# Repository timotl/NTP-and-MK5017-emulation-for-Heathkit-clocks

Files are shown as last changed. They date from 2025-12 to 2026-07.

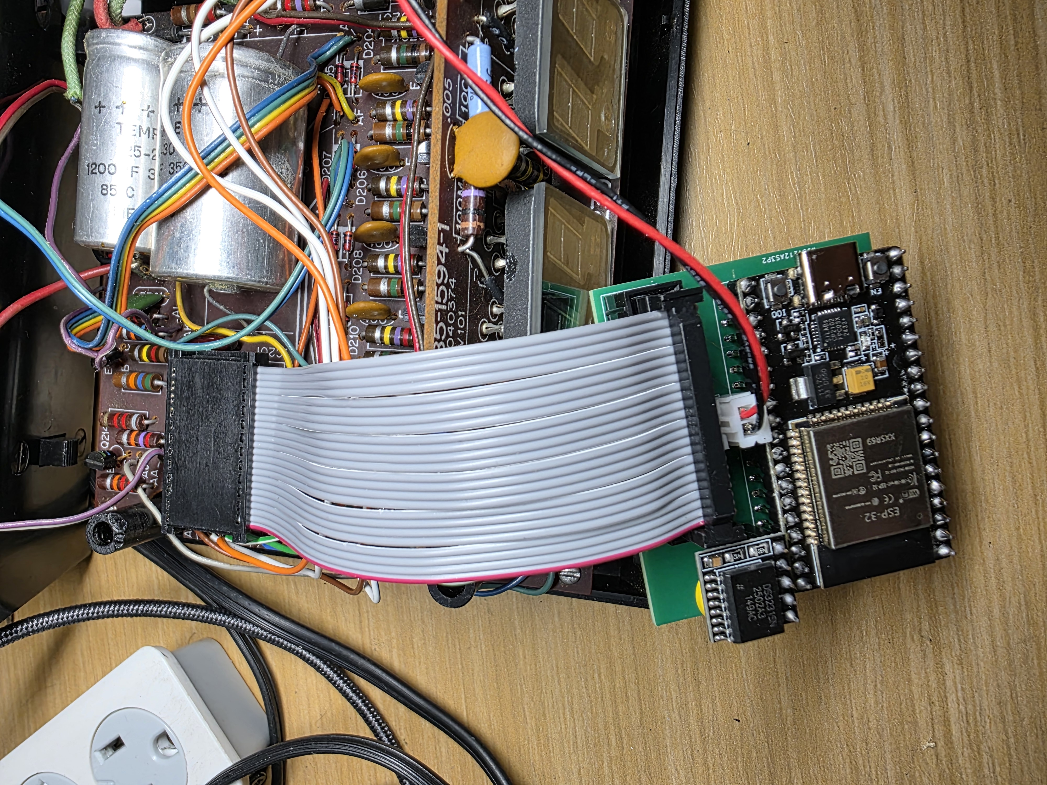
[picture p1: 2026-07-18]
Pictures/PCB Installed.jpg

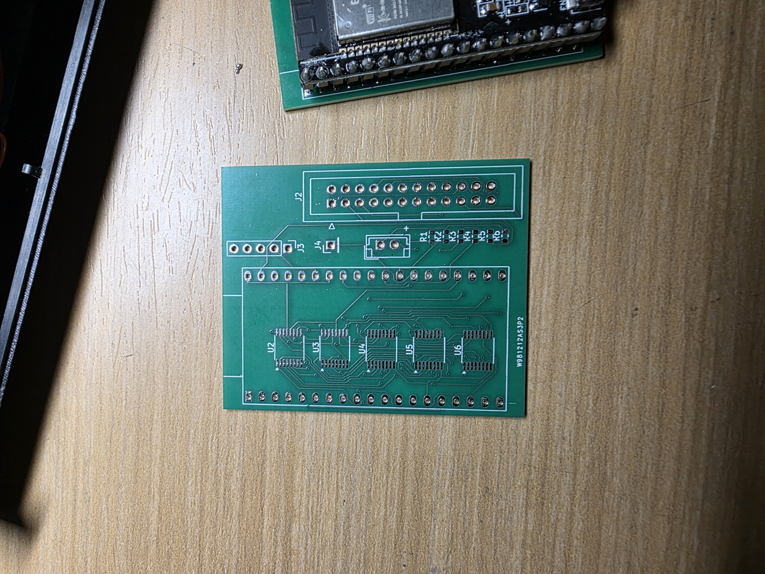
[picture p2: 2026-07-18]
Pictures/PCB Top.jpg

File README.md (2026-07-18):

# NTP-and-MK5017-emulation-for-Heathkit-clocks
Documentation and modification of original clock to use ESP32 module instead of MK5017. 
Uses original chip socket and only requires 5v power module. 
No additional changes to the original hardware. 
Includes schematic and PCB for interface board. 
Full code and description of function. 
Documentation of the MK5017 

ESP32 sketch to replace MK5017AA and BA used in HeathKit panaplex clocks
Requires shift register and level shifting interface which connects to the original board via chip socket
No modifications to the original clock, except adding a 5v power supply module at the 120v input line
Heathkit GC-1092D, Heathkit GC-1005, Heathkit GC-1092A, Heathkit GC-1094 all fully tested
Display updates are state driven and writing to display is handled by hardware timer

WIFI mode:
Portal will be active if the configured wifi settings do not connect or if the time cannot be set from the configured NTP server after 1 minute.
NTP server, timezone, display off times are set through the portal.

ESP Touch (also snooze or alarmoff switches) changes display from Time to Date, Date to display off, display off to on.
GC-1092A/D - Original 555 touch hardware can be used, however each touch event must be at least 5 seconds apart.

MK5017 mode:
Switches and all behavior faithful to original hardware
RTC simulates battery backup of the GC-1092A/D (but works on all models) - Will consider time valid for configurable number of hours.
Note: some RTC modules don't keep time when powered off. Set BatteryBackup to 0 to disable holdover.
Switching modes will reset the model. Set model by pressing Hour/Month switch until the correct model is displayed, then toggle Time Set.

Switching modes:
Holding Hour/Month switch at power up will change between MK5017 and Wifi mode. Display will go from 888888 to ------ and restart

ArduinoOTA mode:
Alarm/Date switch also enters OTA mode. OTA mode uses AP mode with password and times out after 10 min.

Troubleshooting - Toggle Time Set switch 3x in under 5 seconds.
WIFI mode: Restart to portal to adjust WIFI and NTP settings.
MK5017 mode: Restart clearing RTC and model

Select ESP32-WROOM-DA Module in Arduino IDE
Partition scheme "Minimal SPIFFS (1.9MB APP with OTA/190KB SPIFFS) required if SerialBT is enabled

Also includes Manuals and other datasheets for the various models I can find.

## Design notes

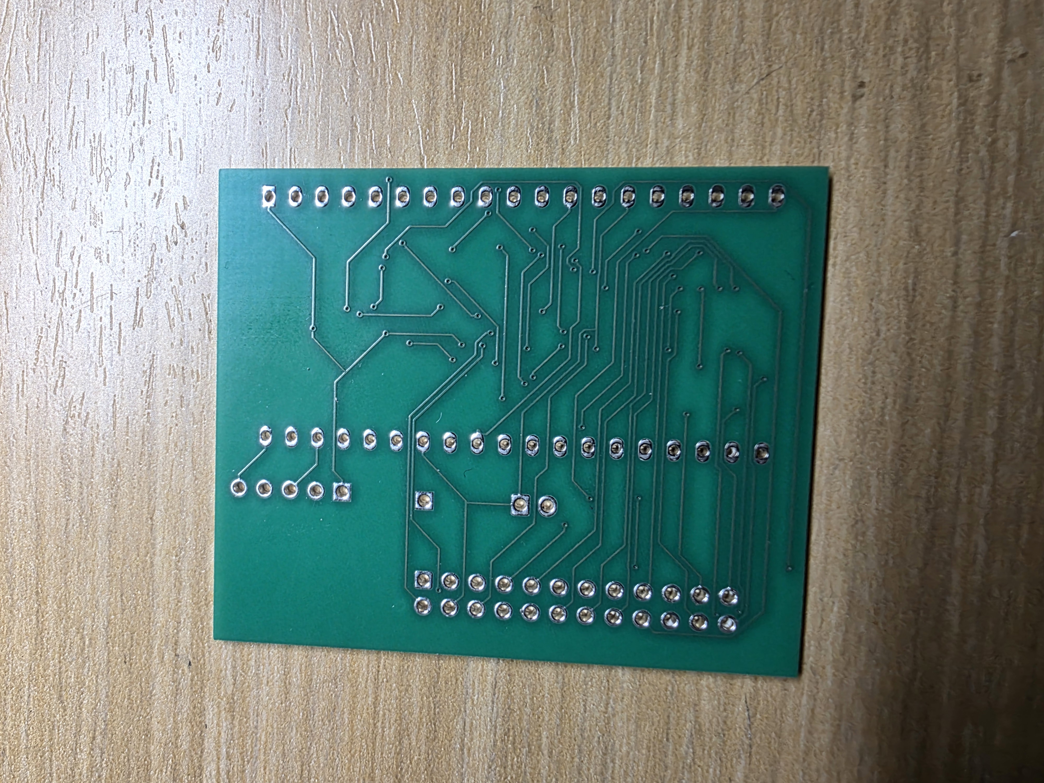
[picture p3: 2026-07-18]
Pictures/PCB Bottom.jpg

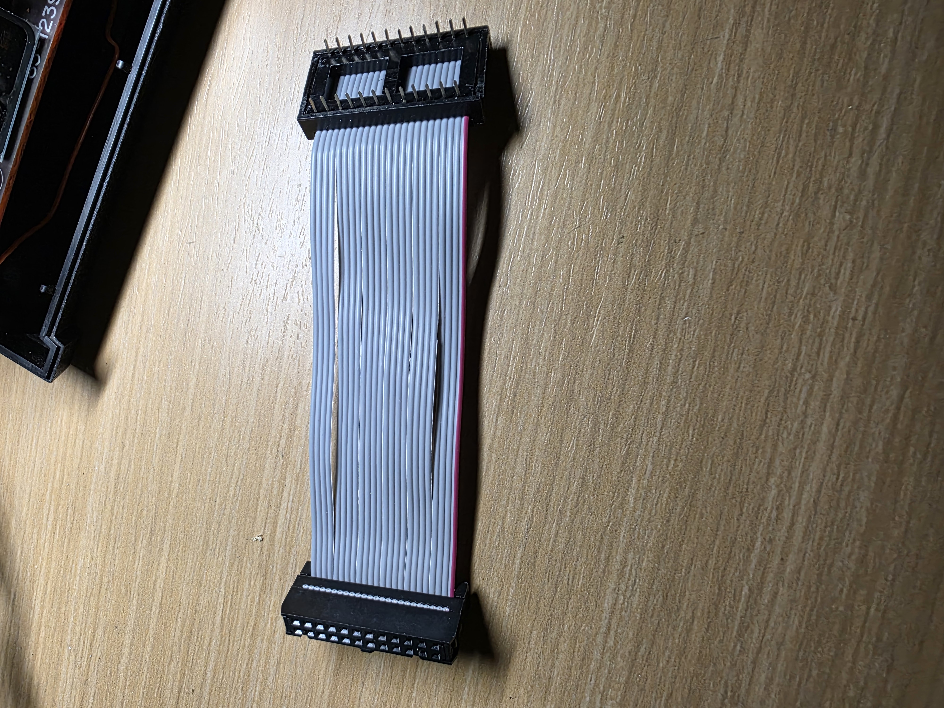
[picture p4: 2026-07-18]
Pictures/Ribbon cable.jpg

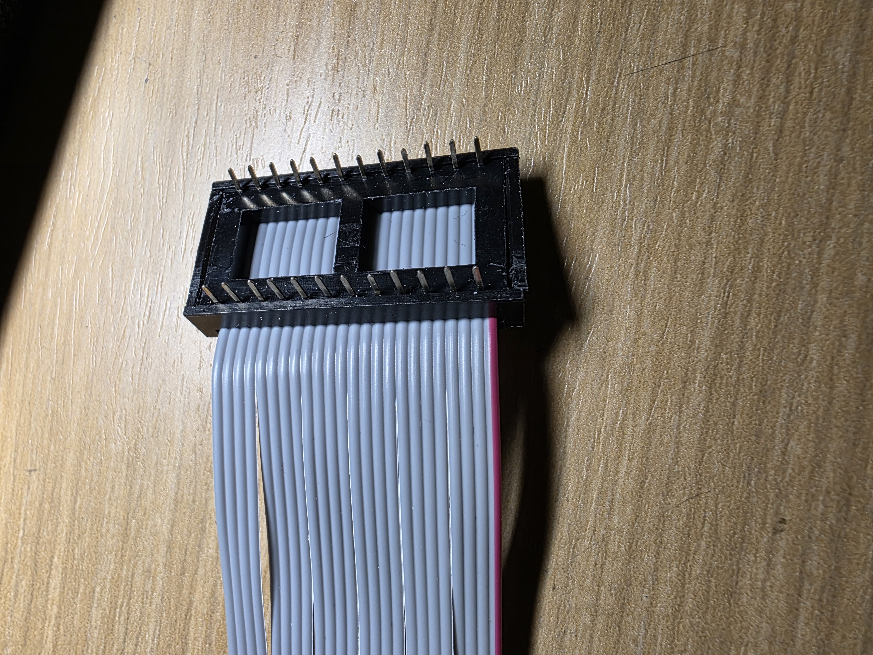
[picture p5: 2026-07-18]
Pictures/Ribbon DIP Plug.jpg

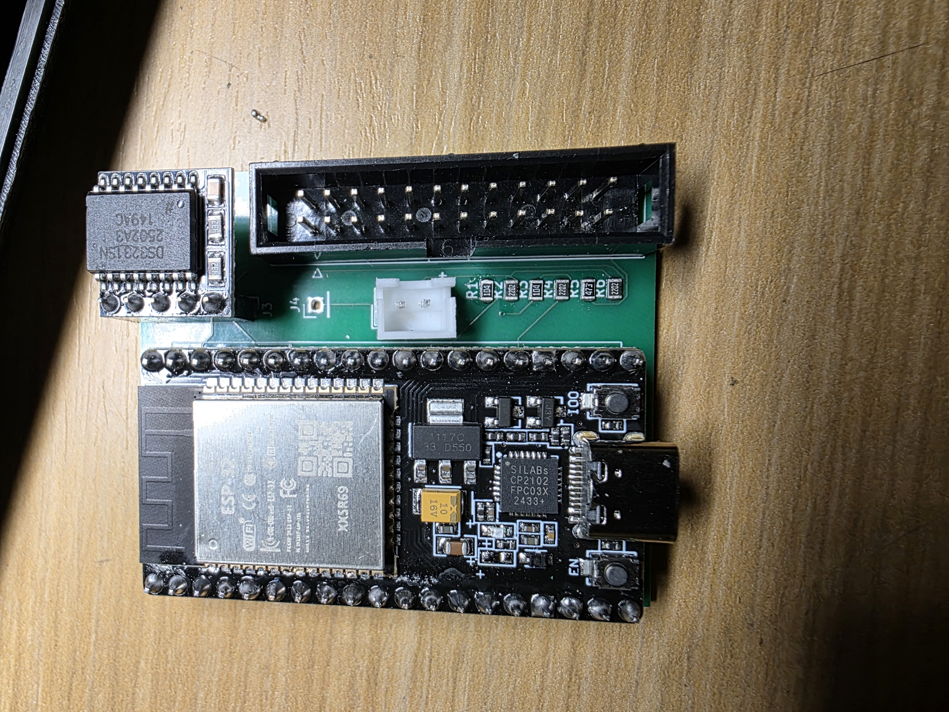
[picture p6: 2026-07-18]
Pictures/PCB Completed -top.jpg

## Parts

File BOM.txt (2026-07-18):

Parts:
ESP32 - any 38 pin module (NodeMCU etc)
Power supply https://www.digikey.com/en/products/detail/mean-well-usa-inc/IRM-10-5/7704657

DIP plug https://www.digikey.com/en/products/detail/assmann-wsw-components/ADIP-24Z-LC/924324
DS3231 module https://www.digikey.com/en/products/detail/seeed-technology-co-ltd/101990005/5487769
IDC socket and cable or directly solder ribbon.

U2, U3 HC595
U4,5,6 4504

R1 100k
R2 20k
R3 100k
R4 20k
R5 47k
R6 20k

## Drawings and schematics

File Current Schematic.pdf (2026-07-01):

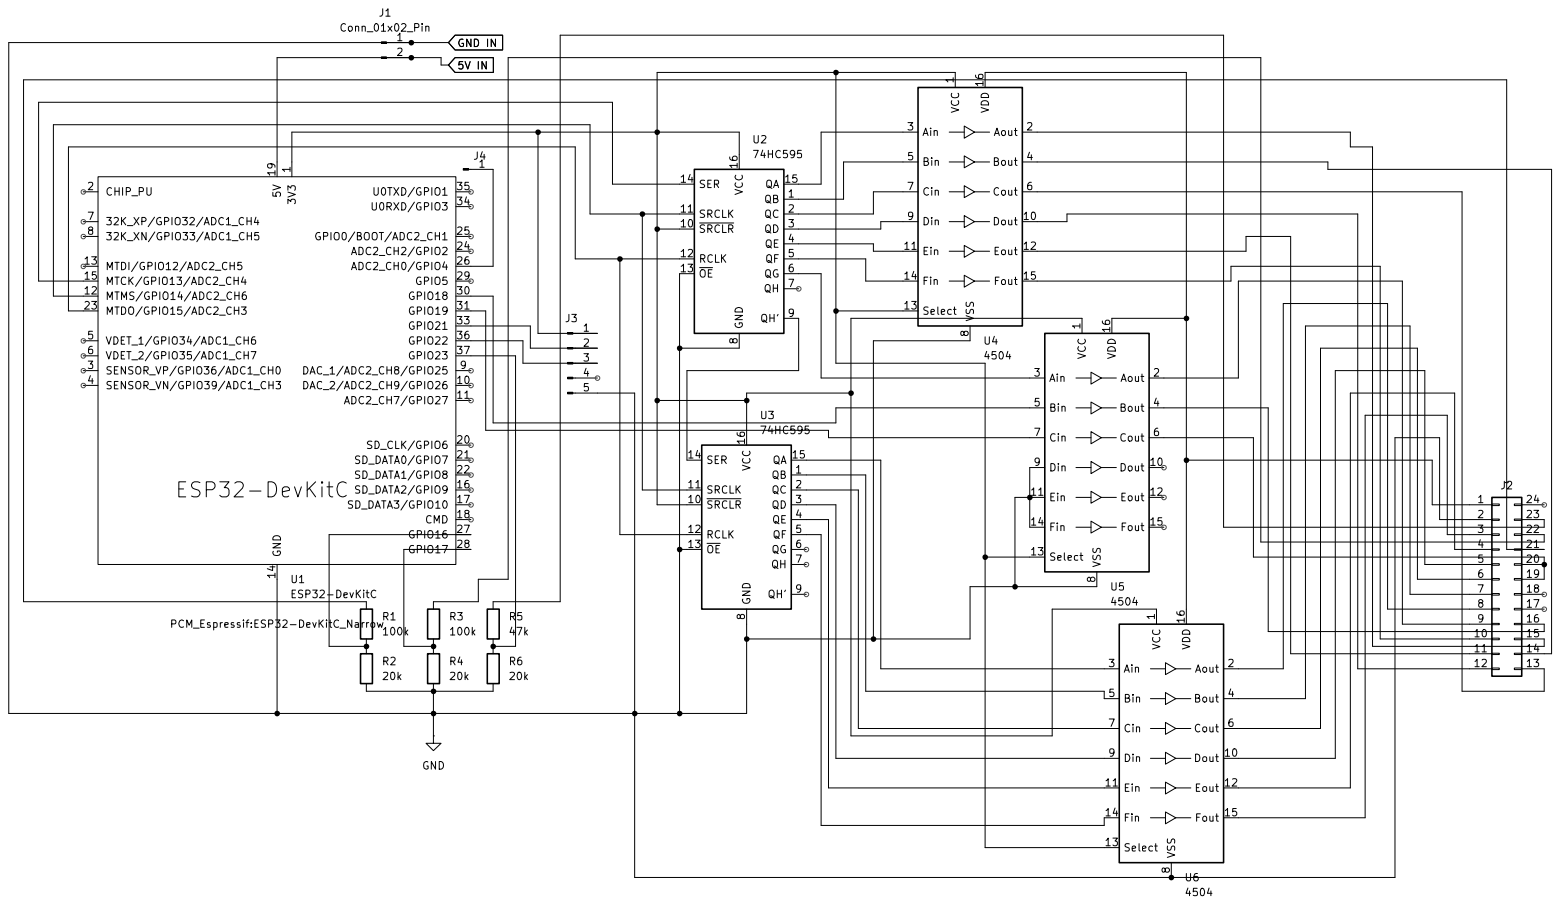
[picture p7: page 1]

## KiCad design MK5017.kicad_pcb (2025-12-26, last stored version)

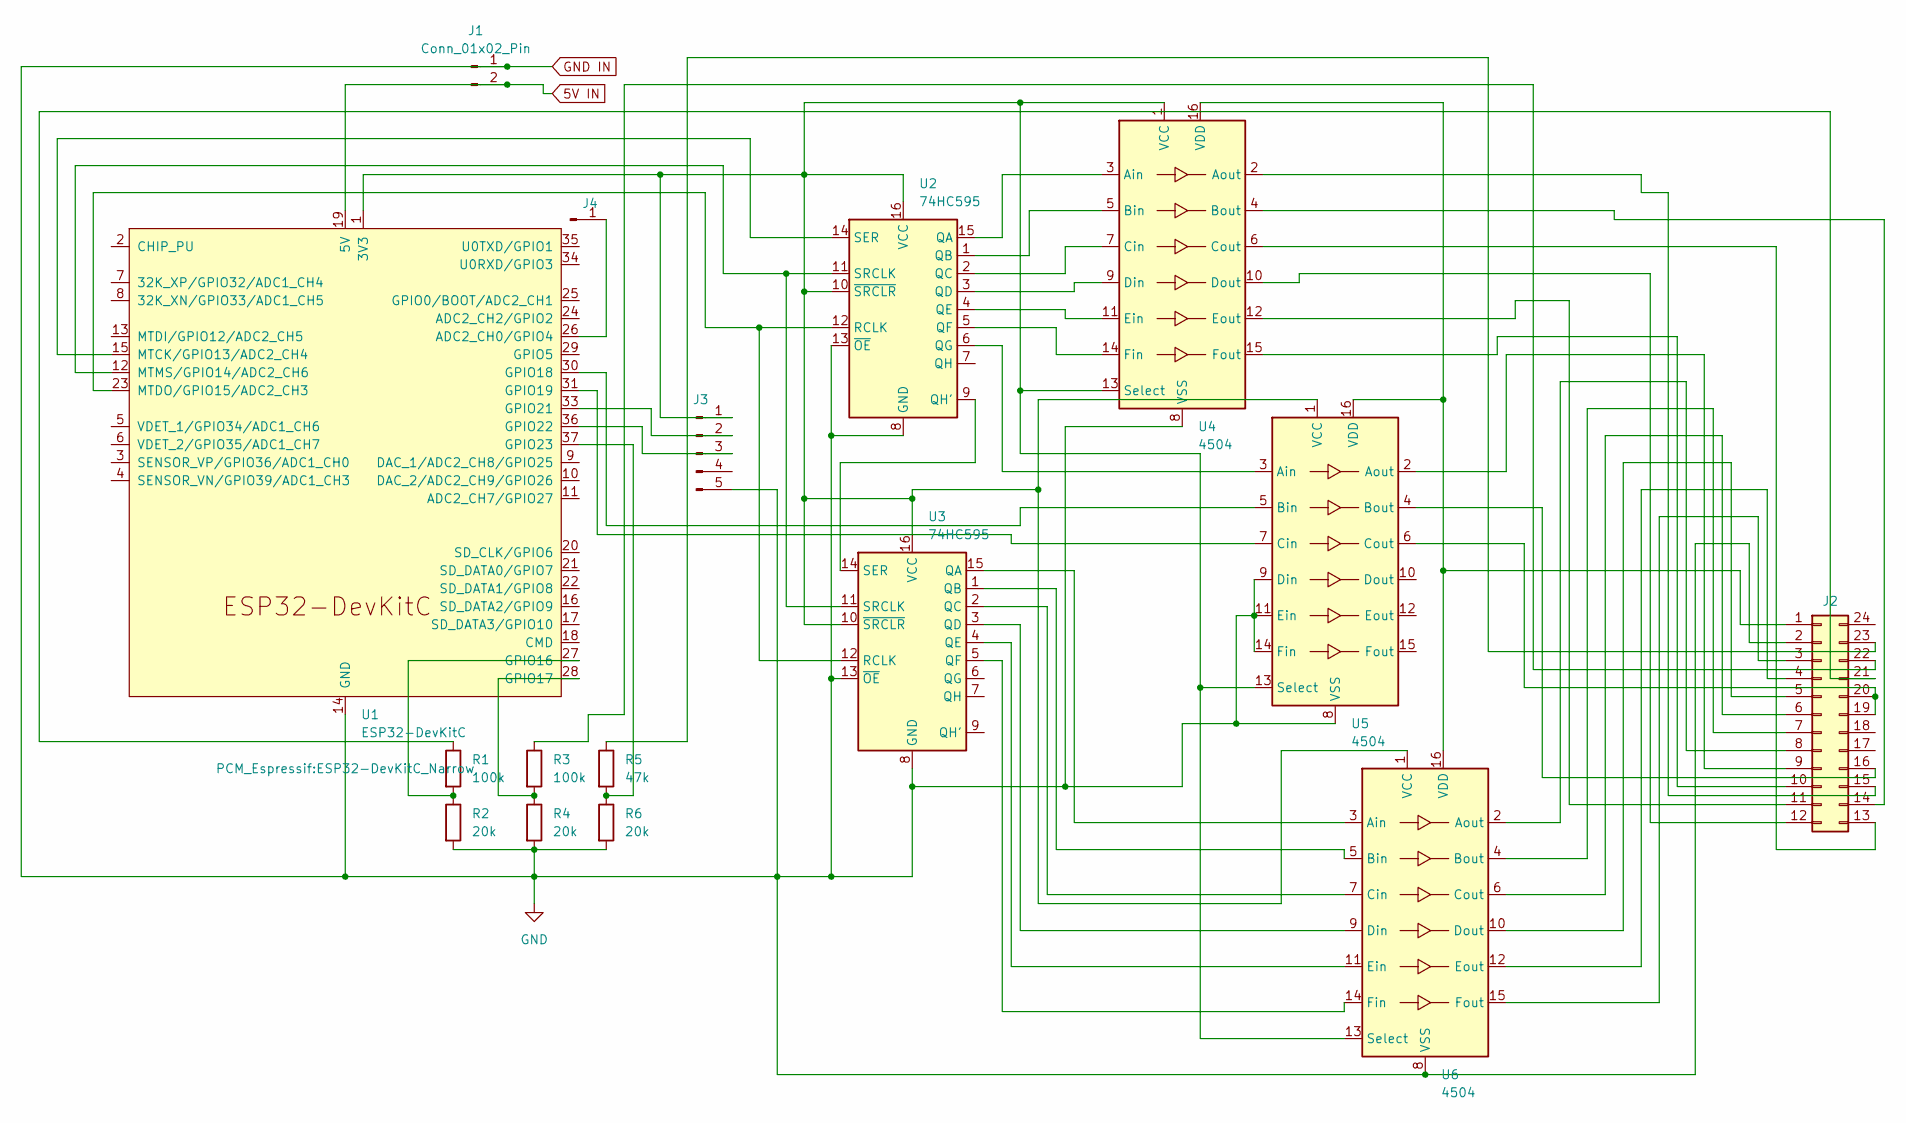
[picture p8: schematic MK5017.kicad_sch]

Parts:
J1: Conn_01x02_Pin; JST_EH_B2B-EH-A_1x02_P2.50mm_Vertical
J2: IDC-Header_2x12_P2.54mm_Vertical
J3: Conn_01x05_Pin; PinHeader_1x05_P2.54mm_Vertical
J4: Conn_01x01_Pin; PinHeader_1x01_P2.54mm_Vertical
R1, R3: 100k; R_0603_1608Metric
R2, R4, R6: 20k; R_0603_1608Metric
R5: 47k; R_0603_1608Metric
U1: ESP32-DevKitC; ESP32-DevKitC_Narrow
U2, U3: 74HC595; TSSOP-16_4.4x5mm_P0.65mm
U4, U5, U6: 4504; TSSOP-16_4.4x5mm_P0.65mm

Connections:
5V IN: J1.2, U1.19 (5V); also elsewhere on the board
GND IN: J1.1, J2.2, J3.5, R2.2, R4.2, R6.2, U1.14 (GND), U1.32 (GND), U1.38 (GND), U2.8 (GND), U2.13 (~OE), U3.8 (GND), U3.13 (~OE), U4.8 (VSS), U5.8 (VSS), U5.9 (Din), U5.11 (Ein), U5.14 (Fin), U6.8 (VSS); also elsewhere on the board
unnamed: J2.1, U4.16 (VDD), U5.16 (VDD), U6.16 (VDD)
unnamed: J2.3, U6.15 (Fout)
unnamed: J2.4, U6.12 (Eout)
unnamed: J2.5, U6.10 (Dout)
unnamed: J2.6, U6.6 (Cout)
unnamed: J2.7, U6.4 (Bout)
unnamed: J2.8, U6.2 (Aout)
unnamed: J2.9, U5.2 (Aout)
unnamed: J2.10, U4.15 (Fout)
unnamed: J2.11, U4.12 (Eout)
unnamed: J2.12, U4.10 (Dout)
unnamed: J2.13, U4.6 (Cout)
unnamed: J2.14, U4.4 (Bout)
unnamed: J2.15, U4.2 (Aout)
unnamed: J2.16, U5.4 (Bout)
unnamed: J2.19, J2.20, U5.6 (Cout)
unnamed: J2.21, R1.1
unnamed: J2.22, R3.1
unnamed: J2.23, R5.1
unnamed: J3.1, U1.1 (3V3), U2.10 (~SRCLR), U2.16 (VCC), U3.10 (~SRCLR), U3.16 (VCC), U4.1 (VCC), U4.13 (Select), U5.1 (VCC), U5.13 (Select), U6.1 (VCC), U6.13 (Select)
unnamed: J3.2, U1.33 (GPIO21)
unnamed: J3.3, U1.36 (GPIO22)
unnamed: J4.1, U1.26 (ADC2_CH0/GPIO4)
unnamed: R1.2, R2.1, U1.27 (GPIO16)
unnamed: R3.2, R4.1, U1.28 (GPIO17)
unnamed: U1.30 (GPIO18), U5.5 (Bin)
unnamed: U1.31 (GPIO19), U5.7 (Cin)
unnamed: R5.2, R6.1, U1.37 (GPIO23)
unnamed: U1.15 (MTCK/GPIO13/ADC2_CH4), U2.14 (SER)
unnamed: U1.23 (MTDO/GPIO15/ADC2_CH3), U2.12 (RCLK), U3.12 (RCLK)
unnamed: U1.12 (MTMS/GPIO14/ADC2_CH6), U2.11 (SRCLK), U3.11 (SRCLK)
unnamed: U2.15 (QA), U4.3 (Ain)
unnamed: U2.1 (QB), U4.5 (Bin)
unnamed: U2.2 (QC), U4.7 (Cin)
unnamed: U2.3 (QD), U4.9 (Din)
unnamed: U2.4 (QE), U4.11 (Ein)
unnamed: U2.5 (QF), U4.14 (Fin)
unnamed: U2.6 (QG), U5.3 (Ain)
unnamed: U2.9 (QH'), U3.14 (SER)
unnamed: U3.15 (QA), U6.3 (Ain)
unnamed: U3.1 (QB), U6.5 (Bin)
unnamed: U3.2 (QC), U6.7 (Cin)
unnamed: U3.3 (QD), U6.9 (Din)
unnamed: U3.4 (QE), U6.11 (Ein)
unnamed: U3.5 (QF), U6.14 (Fin)

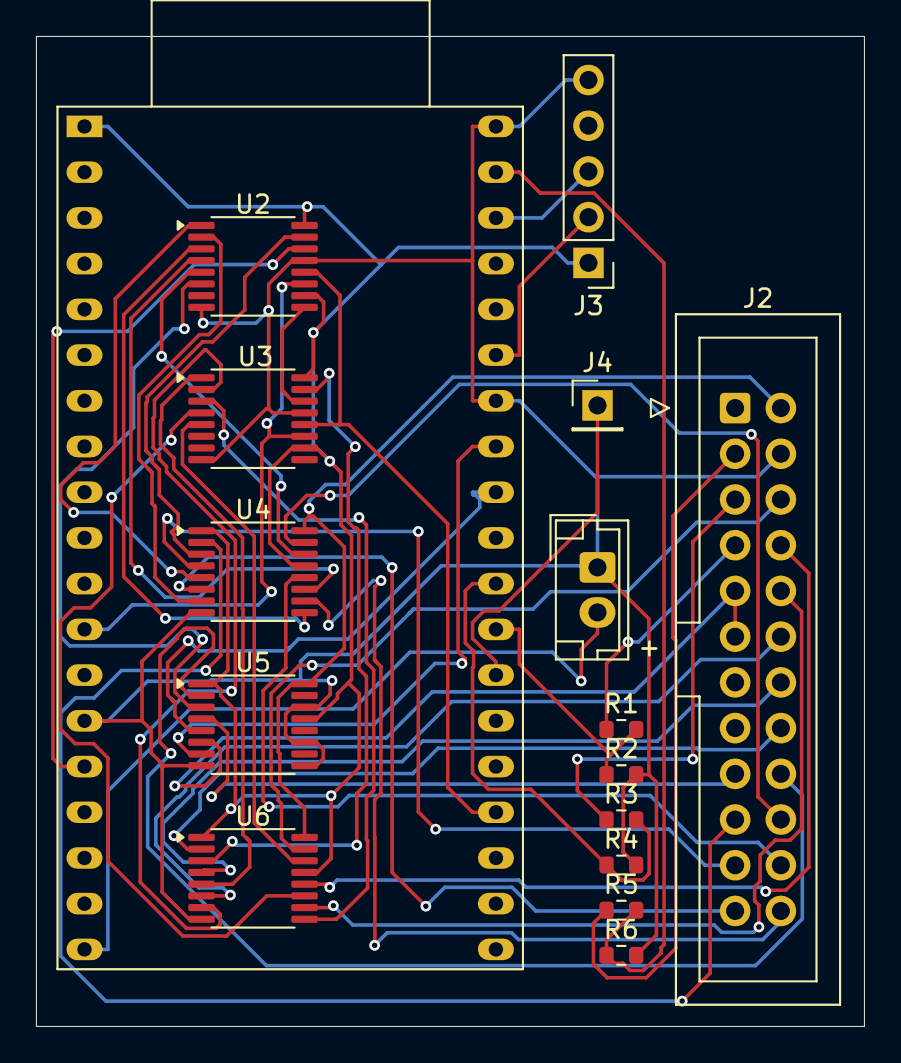
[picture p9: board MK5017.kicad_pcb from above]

Board: 2 copper layers, 46.0 x 55.0 mm, 16 parts (0 on the bottom side), 47 nets.

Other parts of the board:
+: Conn_01x02_Pin; JST_EH_B2B-EH-A_1x02_P2.50mm_Vertical

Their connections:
5V IN: +.2; also elsewhere on the board
GND IN: +.1; also elsewhere on the board

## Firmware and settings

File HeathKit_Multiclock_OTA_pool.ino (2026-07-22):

/*
 Project: MK5017 Replacement
 Description: ESP32 sketch to replace MK5017 used in several HeathKit clocks
 Author: Landon Timothy
 Date: 7.22.2026

 License: MIT License

 Both the software code in this repository and the accompanying
 hardware design files are open-source.

 Permission is hereby granted, free of charge, to any person obtaining
 a copy of this software and associated documentation files, to deal
 in the Software and hardware designs without restriction, including
 without limitation the rights to use, copy, modify, merge, publish,
 distribute, sublicense, and/or sell copies.
 ====================================================================

ESP32 sketch to replace MK5017AA and BA used in HeathKit panaplex clocks
Requires shift register and level shifting interface which connects to the original board via chip socket
No modifications to the original clock, except adding a 5v power supply module at the 120v input line
Heathkit GC-1092D, Heathkit GC-1005, Heathkit GC-1092A, Heathkit GC-1094 all fully tested
Display updates are state driven and writing to display is handled by hardware timer

WIFI mode:
Portal will be active if the configured wifi settings do not connect or if the time cannot be set from the configured NTP server after 1 minute.
NTP server, timezone, display off times are set through the portal.

ESP Touch (also snooze or alarmoff switches) changes display from Time to Date, Date to display off, display off to on.
GC-1092A/D - Original 555 touch hardware can be used, however each touch event must be at least 5 seconds apart.

MK5017 mode:
Switches and all behavior faithful to original hardware. RTC module optional.
RTC simulates battery backup of the GC-1092A/D (but works on all models) - Will consider time valid for configurable number of hours.
Note some RTC modules don't keep time when powered off. Set BatteryBackup to 0 to disable holdover.
Switching modes will reset the model. Set model by pressing Hour/Month switch until the correct model is displayed, then toggle Time Set.

Switching modes:
Holding Hour/Month switch at power up will change between MK5017 and Wifi mode. Display will go from 888888 to ------ and restart

ArduinoOTA mode:
Alarm/Date switch also enters OTA mode. OTA mode uses AP mode with password and times out after 10 min.

Troubleshooting - Toggle Time Set switch 3x in under 5 seconds.
WIFI mode: Restart to portal to adjust WIFI and NTP settings.
MK5017 mode: Restart clearing RTC and model

Select ESP32-WROOM-DA Module in Arduino IDE
Partition scheme "Minimal SPIFFS (1.9MB APP with OTA/190KB SPIFFS) required if SerialBT is enabled
*/

#include <WiFi.h>
#include <WebServer.h>
#include <DNSServer.h>
#include <WiFiManager.h>
#include <ezTime.h>
#include "Arduino.h"
#include <ESPmDNS.h>
#include <WiFiUdp.h>
#include <ArduinoOTA.h>
#include <Preferences.h>
#include <ESP32TimerInterrupt.h>
#include <RTClib.h>
#include "driver/rmt.h"
#include "driver/gpio.h"
#include <driver/pulse_cnt.h>

// Wifi stuff
// Wifi will revert to setup AP mode if no connection available
// OTA mode is triggered and runs in AP mode with timeout
WiFiManager wifiManager;
String wifihostname = "Heathkit-Clock";        // Hostname of ESP device
String wifisetupssid = "Heathkit-Clock Setup"; // Setup AP mode SSID - no password
String wifiotassid = "Heathkit-OTA";           // OTA AP mode SSID
String wifiotapass = "update123";              // OTA AP mode password
bool CP_Changes = 0;                           // Flag for pending CP changes
bool UseCPStartup;                             // Flag for CP on startup

#define USE_BT 1                // compile-time switch for BluetoothSerial -- Requires partition scheme "Minimal SPIFFS (1.9MB APP with OTA/190KB SPIFFS)"

int ntpinterval = 500;          // NTP update interval
ezDebugLevel_t ntpdebug = INFO; // ezTime debug level
RTC_DS3231 rtc;                 // RTC instance only for MK5017 emulation mode
int CurrentYear = 2026;         // RTC Current year seed (1092D MK5017 only) Original hardware does not have a year, but for RTC emulation we have a proper calendar
int BatteryBackup = 6;          // Hours to consider 'Battery backup' valid
int showdatesec = 10;           // Seconds to show date when touched
bool RTCPresent = false;        // Automatic flag for RTC presence

// Should not need to change anything below here
// BT stuff - Replace hardware serial with BluetoothSerial if USE_BT is true
#if USE_BT
#include "BluetoothSerial.h"
BluetoothSerial SerialBT;
#define Serial SerialBT // Rename Serial to SerialBT for all Serial calls
#define STOP_BT() SerialBT.end()
#else
#define STOP_BT()
#endif

// Time of day and day of week blanking - WIFI mode only, set via Captive Portal
bool timeBlankingEnabled; // enable/disable time blanking, loaded from persistent config
String ontime;            // 24 hour time hhmmss, loaded from persistent config
String offtime;           // 24 hour time hhmmss, loaded from persistent config
String weekendDay1;       // days to blank display, loaded from persistent config
String weekendDay2;       // days to blank display, loaded from persistent config
String ntpserver;         // NTP server name, loaded from persistent config

char timeZoneBuf[64] = "";
char blankingBuf[4] = "0";
// Timezone and NTP setup  ezTime https://github.com/ropg/ezTime
// POSIX definitions for local timezone selection in captive portal
// Generated for North American timezones via Captive Portal
constexpr const char *DEFAULT_TIMEZONE_POSIX = "MST7MDT,M3.2.0/2,M11.1.0/2"; // America/Denver timezone definition including DST On/Off
String localTzPosix = DEFAULT_TIMEZONE_POSIX;
Timezone tz;

// Pin definitions
const uint8_t pinData = 13;  // shift register data
const uint8_t pinClock = 14; // shift register clock
const uint8_t pinLatch = 15; // shift register latch
const uint8_t pinKA = 17;    // KA pin on socket (22)
const uint8_t pinKB = 16;    // KB pin on socket (21)
// Handbuilt board is backwards
// const uint8_t pinKA = 16;    // KA pin on socket (22)
// const uint8_t pinKB = 17;    // KB pin on socket (21)

const uint8_t pinTouch = 4;  // Touch input
const uint8_t pinAM = 18;    // AM pin on socket (16)
#define RMT_PIN GPIO_NUM_19  // Tone pin on socket (20)
const int sw_HOLD_Pin = 23;  // 60Hz pin on socket (23)
bool Disable_swHOLD = false; // Disable HOLD function in case hardware issue
#define PCNT_UNIT          PCNT_UNIT_0
#define DISCIPLINE_INTERVAL 600000LL // 10 minutes in milliseconds (10 * 60 * 1000)

bool ArduinoOTAEnabled = false;

// NVS persistent configuration
Preferences prefs;

// Alarm tone
#define RMT_CH RMT_CHANNEL_1
static bool toneActive = false;
#define CYCLES_PER_HALFSECOND 425
#define ITEMS_PER_CYCLE 7
#define TOTAL_ITEMS (CYCLES_PER_HALFSECOND * ITEMS_PER_CYCLE)
static rmt_item32_t pulse_items[TOTAL_ITEMS];

// Display stuff
ESP32Timer ITimer1(1); // Timer 1 for display driving
TaskHandle_t displayTaskHandle = nullptr;
const uint32_t T_INTERVAL = 525; // timer interval
const uint8_t NUM_DIGITS = 6;
volatile uint8_t curdigit = 0;
#define SEGS_OFF 0x00   //      all segments off for blanking
#define SEG_INVERT 0x00 //      use 0xff to invert SEG outputs, 0x00 for std SEG output - 00 for MK5717
#define DIG_INVERT 0x00 //      use 0xff to invert DIG outputs, 0x00 for std DIG output - 00 for MK5717
uint8_t displayBuffer[NUM_DIGITS] = {SEGS_OFF, SEGS_OFF, SEGS_OFF, SEGS_OFF, SEGS_OFF, SEGS_OFF};
// Segment pattern key
//    - a -
//   f    b
//   - g -
//   e    c
//   - d -

const uint8_t
    chars[] = //      Segment patterns for characters
    {
        // Dgfedcba
        0b00111111, // 0
        0b00000110, // 1
        0b01011011, // 2
        0b01001111, // 3
        0b01100110, // 4
        0b01101101, // 5
        0b01111101, // 6
        0b00000111, // 7
        0b01111111, // 8
        0b01101111, // 9
        0b01110111, // A  10
        0b01011111, // a  11
        0b00111001, // C  12
        0b01011000, // c  13
        0b01011110, // d  14
        0b01111001, // E  15
        0b01110001, // F  16
        0b00111000, // L  17
        0b01010100, // n  18
        0b00111111, // O  19
        0b01011100, // o  20
        0b01110011, // P  21
        0b01010000, // r  22
        0b01101101, // S  23
        0b01111000, // t  24
        0b00111110, // U  25
        0b00000000, // blank 26
        0b01000000  // Dash  27
};

#define CHAR_BLANK 26
#define CHAR_DASH 27

// Digit pin positions in the digit byte
const uint8_t digits[] = {
    0b10000000,
    0b01000000,
    0b00100000,
    0b00010000,
    0b00001000,
    0b00000100,
};

enum incrementTimeField
{
    Minutes,
    MinuteTens,
    Hours
};

enum incrementUpdateType
{
    UpdateLive,
    UpdateStrings
};

enum DateField
{
    Day,
    Month
};

enum DisplayMode
{
    MODE_TIME,
    MODE_DATE,
    MODE_SET,
    MODE_MESSAGE
};
DisplayMode currentDisplayMode = MODE_MESSAGE;
enum Emulation : uint8_t
{
    WIFI = 0,
    MK5017 = 1,
    EmulationCount
};
enum Model : uint8_t
{
    MODEL_GC_1005 = 0,
    MODEL_GC_1092D = 1,
    MODEL_GC_1092A = 2,
    MODEL_GC_1094 = 3,
    MODEL_BOGUS = 4,
    ModelCount
};
const char *modelToString(Model m)
{
    switch (m)
    {
    case MODEL_GC_1005:
        return "GC-1005";
    case MODEL_GC_1092D:
        return "GC-1092D";
    case MODEL_GC_1092A:
        return "GC-1092A";
    case MODEL_GC_1094:
        return "GC-1094";
    case MODEL_BOGUS:
        return "Unset";
    default:
        return "Unknown";
    }
}

// Display messages in readable form
constexpr int MESSAGE_COUNT = 10;
const uint8_t messagearray[MESSAGE_COUNT][NUM_DIGITS] = {
    {1, 0, 0, 5, CHAR_BLANK, CHAR_BLANK}, // 1005
    {1, 0, 9, 2, 14, CHAR_BLANK},         // 1092D
    {1, 0, 9, 2, 10, CHAR_BLANK},         // 1092A
    {1, 0, 9, 4, CHAR_BLANK, CHAR_BLANK}, // 1094
    {23, 24, 10, 22, 24, CHAR_BLANK},     // S t A r t
    {12, 20, 18, 13, 24, 14},             // C o n c t d
    {23, 15, 24, 25, 21, CHAR_BLANK},     // S E t U P
    {8, 8, 8, 8, 8, 8},
    {CHAR_DASH, CHAR_DASH, CHAR_DASH, CHAR_DASH, CHAR_DASH, CHAR_DASH},
    {CHAR_BLANK, CHAR_BLANK, CHAR_BLANK, CHAR_BLANK, CHAR_BLANK, CHAR_BLANK},
};
int messageindex = 7; // default to eights at startup

constexpr Emulation defaultEmulation = WIFI;
constexpr Model defaultModel = MODEL_BOGUS; // Default to unset model, user must set model for MK5017 emulation
Emulation clockemulation = defaultEmulation;
Model clockmodel = defaultModel;
// end of display stuff

// Switches - debounced switch state tracking. .changed is true for one loop when the state toggles
struct DebouncedSwitch
{
    bool state = false;      // current stable state
    bool changed = false;    // true for one loop when state toggles
    bool lastRead = false;   // last raw sample
    uint32_t lastChange = 0; // micros() of last raw transition
};

DebouncedSwitch sw_1, sw_2, sw_3, sw_4, sw_5, sw_6, sw_7, sw_HOLD;
// static DebouncedSwitch *switches[] = { &sw_1, &sw_2, &sw_3, &sw_4, &sw_5, &sw_6, &sw_7, &sw_HOLD };
const uint32_t debounceDelay = 1000; // 1 ms debounce delay for switches

// Touch input state and event tracking for the ESP/555 touch logic
int threshold = 30;
bool touchActive = false;
bool lastTouchActive = false;
bool gotevent = false;
bool testingLower = true;   // true = trigger on lower than threshold, false = trigger on higher than threshold
int datecounter = 0;        // holds the remaining seconds to keep date visible after touch
bool touchoverride = false; // forces a temporary date display outside normal auto-date timing

// Half-second and second-edge timing used to emulate MK5017 display/update cadence.
bool is24HourMode = false;                  // Default to 12-hour
constexpr uint32_t HALF_OFFSET_US = 500000; // 0.5 s in microseconds
uint32_t secondEdgeMicros = 0;              // micros at the top-of-second edge
volatile bool halfSecond = false;           // will be true for one loop iteration when half-second has elapsed since top-of-second
volatile bool topOfSecond = false;          // will be true for one loop iteration when a new second has started
bool halfSecondFired = false;
volatile int lastMinuteSeen = -1;

// Set Mode Globals
enum EditTarget
{
    EDIT_TIMELIVE,
    EDIT_TIME,
    EDIT_ALARM,
    EDIT_DATE,
    EDIT_MODEL
};

String timestring = "";
uint8_t hr24 = 255;        // 0–23, canonical hour, 255 means unset (always 24 hour time)
uint8_t minutes;           // 0–59
uint8_t seconds;           // 0–59
String datestring = "";    // MMDD format, updated from RTC or NTP
String setstring = "";     // String used for set mode display, updated when incrementing time/date
String displaystring = ""; // String currently displayed
EditTarget activeTarget = EDIT_TIME;
bool inEditMode = false;
bool dateSet = false;
volatile bool dateChanged = false;
bool autoDate = false;

// Alarm globals (MK5017 emulation only)
enum AlarmState
{
    ALARM_IDLE,
    ALARM_ARMED,
    ALARM_SOUNDING,
    ALARM_SNOOZE
};
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
void loop()
{
    CheckSwitches();
    handleTimedDispatches();
    updateDisplayValue();
    handleTouchEvent();
    DispatchSwitches();
    // WIFI mode uses NTP, MK5017 mode uses DS3231 RTC
    if (clockemulation == MK5017)
    {
        if (clockmodel != MODEL_GC_1092D)
        {
            updateAlarm();
            alarmToneDriver();
        }
        // Check model and set if needed
        if (clockmodel == MODEL_BOGUS && !inEditMode)
        {
            handleSetMode(EDIT_MODEL);
        }
    }
    else if (clockemulation == WIFI)
    {
        monitorAndRecoverNtp();
    }
    // OTA mode handling - Done here to avoid the delay entering set Alarm/Date mode while enabling OTA
    if (ArduinoOTAEnabled == true)
    {
        Serial.println("Enabling OTA");
        ArduinoOTA_begin();
        ArduinoOTAEnabled = false;
    }
    ArduinoOTA.handle(); // Standard OTA handling, must be called frequently in loop()
    checkOtaTimeout();   // Check for OTA timeout and revert to normal operation if needed
    events();            // ezTime event handling, must be called frequently in loop()
    // Switch status readout - prints to serial for debugging.
    //   DebouncedSwitch *switches[] = { &sw_1, &sw_2, &sw_3, &sw_4, &sw_5, &sw_6, &sw_7, &sw_HOLD };
    //   const char *labels[] = { "1.TS", "2.AS_DS", "3.H_M", "4.M_D", "5.SN_ACT", "6.AE_ATS", "7.12_24", "SW_HOLD" };
    //  for (int i = 0; i < 8; i++) {
    //    if (switches[i]->changed) {
    //      Serial.print(labels[i]);
    //      Serial.println(switches[i]->state ? " ON" : " OFF");
    //    }
    //  }
    // clear switch changed (readout only) flags at end of loop()
    // for (int i = 0; i < 8; ++i) switches[i]->changed = false;
    // end Switch status readout

    topOfSecond = false;
    halfSecond = false;
} // End of loop

void updateDisplayValue() // Updates display messages but not dynamic content
{
    switch (currentDisplayMode)
    {
    case MODE_TIME:
    {
        for (int i = 0; i < NUM_DIGITS; i++)
        {
            int digit = timestring.charAt(i) - '0';
            if (i == 0 && digit == 0 && !is24HourMode)
            {
                displayBuffer[i] = SEGS_OFF; // blank leading zero in 12hr
            }
            else
            {
                displayBuffer[i] = chars[digit];
            }
        }
        break;
    }
    case MODE_DATE:
    {
        if (clockemulation == WIFI || clockmodel == MODEL_GC_1092D)
        {
            int len = datestring.length();
            for (int i = 0; i < NUM_DIGITS; i++)
            {
                if (i < len)
                {
                    int digit = datestring.charAt(i) - '0';
                    if (i == 0 && digit == 0)
                    {
                        displayBuffer[i] = SEGS_OFF; // blank leading zero
                    }
                    else
                    {
                        displayBuffer[i] = chars[digit];
                    }
                }
                else
                {
                    displayBuffer[i] = chars[CHAR_BLANK]; // Fill remaining digits with blanks
                }
            }
        }
        else
        {
            currentDisplayMode = MODE_TIME;
            Serial.println("Date display not supported in MK5017 mode for this model, reverting to time display");
        }
        break;
    }
    case MODE_SET:
    {
        int len = displaystring.length();
        for (int i = 0; i < NUM_DIGITS; i++)
        {
            if (i < len)
            {
                int digit = displaystring.charAt(i) - '0';
                if (i == 0 && digit == 0 && (!is24HourMode || activeTarget == EDIT_DATE))
                {
                    displayBuffer[i] = SEGS_OFF; // blank leading zero in 12hr
                }
                else
                {
                    displayBuffer[i] = chars[digit];
                }
            }
            else
            {
                displayBuffer[i] = chars[CHAR_BLANK]; // Fill remaining digits with blanks
            }
        }
        break;
    }
    case MODE_MESSAGE:
    {
        for (int i = 0; i < NUM_DIGITS; i++)
        {
            displayBuffer[i] = chars[messagearray[messageindex][i]];
        }
        break;
    }
    }
}

void updateDisplayStateIfNeeded()
{                                                 // Compute current time/day and decide whether the display should be shown or blanked.
    int currentTime = tz.dateTime("His").toInt(); // HHMMSS as int
    String currentDay = tz.dateTime("l");

    if (!sw_HOLD.state)
    { // Update time and date so they are never stale, except hold
        timestring = tz.dateTime(is24HourMode ? "His" : "his");
        datestring = tz.dateTime("md");
    }
    static bool manualDisplayOn = false;  // Manual ON until next interval
    static bool manualDisplayOff = false; // Manual OFF until next interval
    int ontimeint = ontime.toInt();
    int offtimeint = offtime.toInt();
    bool isWeekend = (currentDay == weekendDay1 || currentDay == weekendDay2);
    bool withinDisplayWindow = !timeBlankingEnabled || (currentTime >= ontimeint && currentTime < offtimeint && !isWeekend);

    if (clockemulation == MK5017)
    {
        if (gotevent)
        {
            touchoverride = true;
            datecounter = 5;
            currentDisplayMode = MODE_DATE;
            gotevent = false;
        }
        if (clockmodel == MODEL_BOGUS)
            return;

        // 1092D date stuff
        if (clockmodel == MODEL_GC_1092D && !inEditMode)
        {
            if (autoDate || touchoverride)
            {
                if ((tz.second() % 10 == 8) || (tz.second() % 10 == 9))
                {
                    currentDisplayMode = MODE_DATE;
                    // Serial.println("matches 8/9 sec - autodate on");
                }
                else if (currentDisplayMode != MODE_TIME && !touchoverride)
                {
                    currentDisplayMode = MODE_TIME;
                    // Serial.println("Setting back mode_time - autodate on");
                }
            }

            if (datecounter > 1 && (!autoDate || touchoverride))
            {
                datecounter--;
            }
            else if (currentDisplayMode == MODE_DATE && (!autoDate || touchoverride))
            {
                datecounter = 0;
                if (touchoverride)
                    touchoverride = false;
                currentDisplayMode = MODE_TIME;
            }
        }
        return;
    }

    if (gotevent)
    {
        // Caught touch event, ESP pin or computed by switch states
        Serial.print("Touch event detected: ");
        if (currentDisplayMode == MODE_TIME)
        {
            currentDisplayMode = MODE_DATE;
            Serial.println("Show date");
            touchoverride = true;
            datecounter = (clockemulation == WIFI) ? showdatesec : 5;
        }
        else if (currentDisplayMode == MODE_DATE && clockemulation == WIFI)
        {
            currentDisplayMode = MODE_MESSAGE;
            messageindex = 9;
            datecounter = 0;
            touchoverride = false;
            Serial.println("Blank display");
            manualDisplayOff = true;
            manualDisplayOn = false;
        }
        else if (currentDisplayMode == MODE_MESSAGE && messageindex == 9)
        {
            currentDisplayMode = MODE_TIME;
            manualDisplayOn = true;
            manualDisplayOff = false;
            Serial.println("Show time");
        }
        gotevent = false;
    }

    if (datecounter > 0 && currentDisplayMode == MODE_DATE)
    {
        datecounter--;
    }
    else if (currentDisplayMode == MODE_DATE)
    {
        if (datecounter == 0)
        {
            Serial.println("Datecounter timed out - Show time");
            if (touchoverride)
                touchoverride = false;
            currentDisplayMode = MODE_TIME;
        }
    }

    if (withinDisplayWindow && manualDisplayOn)
    {
        manualDisplayOn = false;
        Serial.println("Inside display window - Resetting manualDisplayOn");
    }
    if (!withinDisplayWindow && manualDisplayOff)
    {
        manualDisplayOff = false;
        Serial.println("Outside display window - Resetting manualDisplayOff");
    }

    if (currentDisplayMode != MODE_DATE)
    {
        if ((!withinDisplayWindow || manualDisplayOff) && !manualDisplayOn)
        {
            currentDisplayMode = MODE_MESSAGE;
            messageindex = 9;
        }
        if ((withinDisplayWindow || manualDisplayOn) && !manualDisplayOff)
        {
            currentDisplayMode = MODE_TIME;
        }
    }

    updateDisplayValue();
}
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

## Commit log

2025-12-26 KiCAD Schematic and PCB layout
    [MK5017.kicad_pcb, MK5017.kicad_sch]
2026-06-14 Interface board KiCad package
    Schematic and board layout with gerber files for interface board.
2026-07-01 Enhance README with detailed emulation instructions
    Expanded documentation for NTP and MK5017 emulation, detailing ESP32 sketch, WIFI mode, MK5017 mode, and troubleshooting steps.
2026-07-01 Correct power module voltage requirement in README
    Updated power module requirement from 5v to 3.3v.
2026-07-01 Update power module requirement from 3.3v to 5v
2026-07-17 Clarify ESP32 sketch details and troubleshooting in README
    Updated README to clarify ESP32 sketch compatibility and testing details for HeathKit clocks. Added troubleshooting instructions and refined language for clarity.
2026-07-18 Update README with RTC module note
    Added note about RTC modules and battery backup settings.
2026-07-18 PCB pictures
2026-07-18 Create BOM.txt with parts and specifications
    Added a bill of materials (BOM) listing components and their specifications.
2026-07-22 Switch timekeeping for emulation from RTC to PCNT hardware pulse counter
